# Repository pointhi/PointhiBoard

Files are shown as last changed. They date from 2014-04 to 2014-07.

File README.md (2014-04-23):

PointhiBoard
============

A Raspberry Pi board which is optimized for standalone robotic and automation applications

**Licence:** GNU GPLv3

**work status:** still in Developing

###Required Software

* Eagle V6 or higher
* XC8-Compiler from Microchip

PointhiBoard Bootscreen

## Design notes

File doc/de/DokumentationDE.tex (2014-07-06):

\documentclass[a4paper,10pt]{article}
%\documentclass[a4paper,10pt]{scrartcl}

\usepackage[utf8]{inputenc}

\usepackage{multirow}

\usepackage{graphicx}
  \graphicspath{ {../images/} }
  
\usepackage{color}
  \definecolor{lbcolor}{rgb}{0.9,0.9,0.9}
  \definecolor{lbkeywordcolor}{rgb}{0,0,0.89}
  \definecolor{lbcommentcolor}{rgb}{0.58,0.58,0.58}
  \definecolor{lbstringcolor}{rgb}{0.8,0.48,0}
  \definecolor{pathcolor}{rgb}{0.4,0.4,0.4}

\usepackage{listings}
\lstset{
  tabsize=4,
  basicstyle=\ttfamily,
  showstringspaces=false,
  backgroundcolor=\color{lbcolor},  
  keywordstyle=\color{lbkeywordcolor},
  commentstyle=\color{lbcommentcolor},
  stringstyle=\color{lbstringcolor},
  breaklines=true,
  %frame=single,
  columns=fullflexible,
  xleftmargin=0.5cm,
  xrightmargin=0.5cm,
  framexleftmargin=0.25cm,
  framexrightmargin=0.25cm,
  %prebreak={\\}
}

%\lstdefinelanguage{bash} {
%  morekeywords={sudo,echo}
%}

\newcommand{\path}[1]{\textcolor{pathcolor}{\textbf{#1}}} %texttt

\makeatletter
\def\blfootnote{\xdef\@thefnmark{}\@footnotetext}
\makeatother

\usepackage{verbatim}

\usepackage{hyperref}
\hypersetup{
  colorlinks=true,
  linkcolor=black
}

\title{PointhiBoard Dokumentation}
\author{Thomas Pointhuber}
\date{}

\pdfinfo{
  /Title    (Pointhi Board Dokumentation)
  /Author   (Thomas Pointhuber)
  /Creator  (Thomas Pointhuber)
  /Producer ()
  /Subject  ()
  /Keywords (Raspberry Pi Shield)
}

\begin{document}
\maketitle

\pdfbookmark{\contentsname}{toc}

\tableofcontents

\section{Einleitung}

Der Raspberry Pi ist ein einfacher Einplatinencomputer, welcher ideal für komplexe Steuerungs-/Regelungs- aufgaben im Bereich der Robotik, Hausautomatisierung, und vielen anderen Bereichen ist.\\
Er zeichnet sich durch einen niedrigen Stromverbrauch in Verbindung mit einer großen Anzahl von Schnittstellen, angefangen von USB und LAN über Bussysteme wie SPI und I2C bis zu einzelnen Digitalen Ausgängen, welche mithilfe von Linux angesprochen werden können.\\
Die Nutzung der Low-Level Schnittstellen die an einer Stiftleiste herausgeführt sind gestaltet sich aber nicht immer Trivial, auch ist die Spannungsversorgung in Robotern nicht für eine zusätzliche Last mit bis zu 1A ausgelegt. Aus diesem und anderen Gründen soll daher ein Erweiterungsboard für den Raspberry Pi entstehen welches grundlegende Aufgaben übernimmt, die für Systeme in Steuerungssystemen notwendig erscheinen.\\
%\includegraphics[width=\textwidth]{pointhiboard_booting}

\newpage

\subsection{Überblick der Funktionen}
Die Grundlegenden Ausstattung, die die Erweiterungsplatine besitzen soll, bzw. bereits besitzt.
\begin{itemize}
 \item Effizienter Spannungsregler der Spannungen zwischen 7V-25V auf saubere 5V regelt
 \item Pegelwandler für I2C, um sich mit normaler 5V-Hardware  zu verbinden
 \item Schnittstelle für LCD-Touch-Display auf SPI-Basis, welche später auch für SPI$\rightarrow$CAN Konverter benutzt werden kann.
 \item Echtzeituhr (RTC), weil der Raspberry Pi keine besitzt, diese aber für diverse Anwendungen benötigt werden
 \item Spannungsüberwachung und Überstromschutz, um auch mit LiPo-Versorgung sicher zu arbeiten (Tiefentladeschutz)
 \item Digitale Ein/Ausgänge und 8 Analoge Eingänge um ohne zusätzlicher Erweiterungsboard bereits einfache Steuerungen zu realisieren.
 \item RS232-TTL Schnittstelle
 \item RN-Standard Steckverbinder mit Verriegelung, für einfache Erweiterbarkeit und Betriebssicherheit.
\end{itemize}

\section{Technische Spezifikationen}

\subsection{Mechanische Spezifikationen}

\begin{center}
    \begin{tabular}{| l | l | l | l | l |}
    \hline
    \textbf{Characteristic} & \textbf{Min} & \textbf{Typ.} & \textbf{Max} & \textbf{Units} \\ \hline
    Breite & - & 60 & - & mm \\ \hline
    Länge & - & 110 & - & mm \\ \hline
    
    \end{tabular}
\end{center}

\subsection{Elektrischer Spezifikationen}

\begin{center}
    \begin{tabular}{| l | l | l | l | l | l | l |}
    \hline
    \textbf{Characteristic} 	& \textbf{Symbol} 	& \textbf{Test Conditions} 	& \textbf{Min} 	& \textbf{Typ.} & \textbf{Max} 	& \textbf{Units} \\ \hline
    Versorgungsspannung 	& $U_{IN}$ 		& 				& 8 		& 12 		& 20 		& $V$ \\ \hline
    Eingangsstrom 		& $I_{IN}$ 		& 				& - 		& - 		& 8 		& $A$ \\ \hline
    Leerlaufstrom 		& $I_{IN0}$ 		& $U_{IN} = 12V$		& - 		& 20 		& - 		& $mA$ \\ \hline
    Ausgangsspannung, 5V	& $U_{5V}$ 		& 				& 4.95 		& 5 		& 5.05 		& $V$ \\ \hline
    Ausgangsstrom, 5V 		& $I_{5V}$ 		& 				& - 		& - 		& 2.5 		& $A$ \\ \hline
    Umgebungstemperatur 	&  			& 				& -10 		& 20 		& 50 		& $^\circ C$ \\ \hline
    \end{tabular}
\end{center}

\subsubsection{Steckverbinder}

\paragraph{I2C} \mbox{} \\
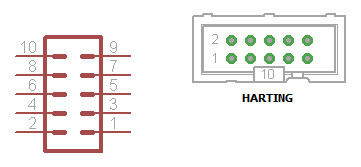
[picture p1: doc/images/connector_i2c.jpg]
 \\
Der I2C-Stecker dient dazu Peripherie mit Spannung und einem Busdystem zu verbinden (I2c). Er ist gemäß den RN-Definitionen\footnote{\url{http://www.rn-wissen.de/index.php/RN-Definitionen\#I2C-Bus_Stecker}} belegt.
\begin{center}
    \begin{tabular}{| l | l |}
    \hline
    Pin 1 	& SCL (Taktleitung) \\ 
    Pin 3	& SDA (Datenleitung) \\
    Pin 5,7 	& +5V \\ 
    Pin 9 	& Batteriespannung \\ 
    Pin 2,4,6,8	& GND \\
    Pin 10 	& INT \\ \hline
    \end{tabular}
\end{center}

\paragraph{ICSP} \mbox{} \\
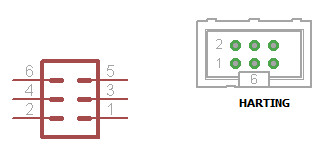
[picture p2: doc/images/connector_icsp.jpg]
 \\
Der ICSP-Verbinder ist dazu vorhanden um den PIC mit einer Firmware beschreiben zu können. Er ist nicht als 5-Poligen Stiftleiste wie er oft realisiert wird ausgeführt, sondern als verpolungssicherer 6-Poliger Steckverbinder wie ich ihn in allen meinen anderen Schaltungen auch verwende.
\begin{center}
    \begin{tabular}{| l | l |}
    \hline
    Pin 1 	& PGD \\ 
    Pin 2,4	& VSS (GND) \\
    Pin 3 	& PGC \\ 
    Pin 5 	& VDD (+5V) \\ 
    Pin 6	& MCLRE/VPP \\ \hline
    \end{tabular}
\end{center}

\paragraph{8-Bit Datenportstecker} \mbox{} \\
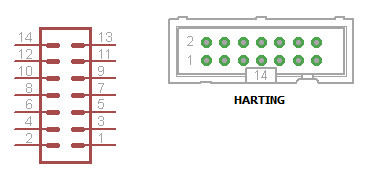
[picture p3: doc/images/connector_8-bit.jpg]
 \\
Es können hier 8 Signale übertragen werden, welche je nach Steckverbinder Analog oder Digital sein können.
\begin{center}
    \begin{tabular}{| l | l |}
    \hline
    Pin 1...8 	& PIN 0...7 \\ 
    Pin 9,11	& +5V \\
    Pin 10,12,14& GND \\ 
    Pin 13 	& Batteriespannung \\ \hline
    \end{tabular}
\end{center}

\paragraph{RS232-TTL} \mbox{} \\
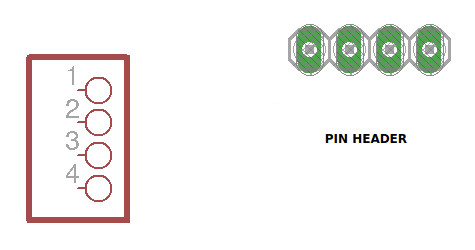
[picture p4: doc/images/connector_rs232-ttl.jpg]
 \\
Der RS232-TTL-Stecker ist gemäß den RN-Definitionen\footnote{\url{http://www.rn-wissen.de/index.php/RN-Definitionen\#RS232_TTL_Stecker}} belegt.
\begin{center}
    \begin{tabular}{| l | l |}
    \hline
    Pin 1 	& RX \\ 
    Pin 2	& TX \\
    Pin 3	& GND \\ 
    Pin 4 	& +5V \\ \hline
    \end{tabular}
\end{center}

%\section{Prototyp}

%Ich habe bereits einen Prototypen gebaut, der die grundlegende Funktionalität abdeckt, und als Testsystem dient. Das Linux-System bootet, und auch der Steuerungs-Chip auf dem Board arbeitet einwandfrei. Bis zu diesem Stand musste ich aber viele Probleme lösen, und deshalb wird bald eine neue Platine entstehen in der diese Probleme nicht mehr existent sind. \\ \\
%\includegraphics[width=\textwidth]{pointhiboard_prototype_booting} \\
%Das Board bekam bereits ein neues Layout, welches unter anderem Masseschleifen entfernte, und Status LEDs beinhaltet, die ein einfaches Debuggen ermöglichen sollen. Auch wurde der Schaltregler optimiert, welcher für das Board essentiell ist. \\

\newpage
\section{Platine}

\subsection{Übersicht}

\subsubsection{Top-Layer}

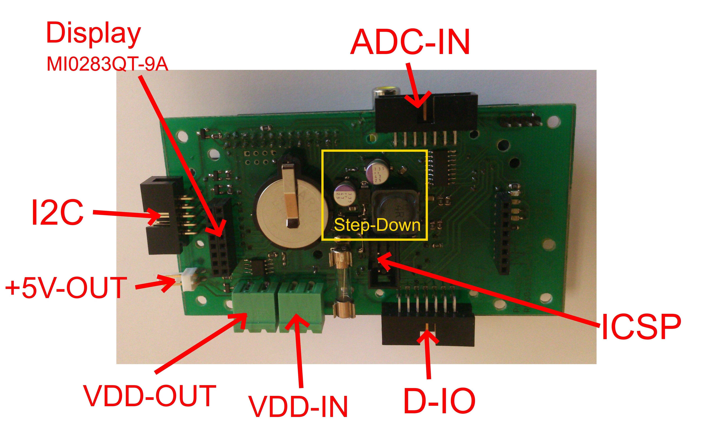
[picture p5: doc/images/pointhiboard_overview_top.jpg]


\subsubsection{Bottom-Layer}

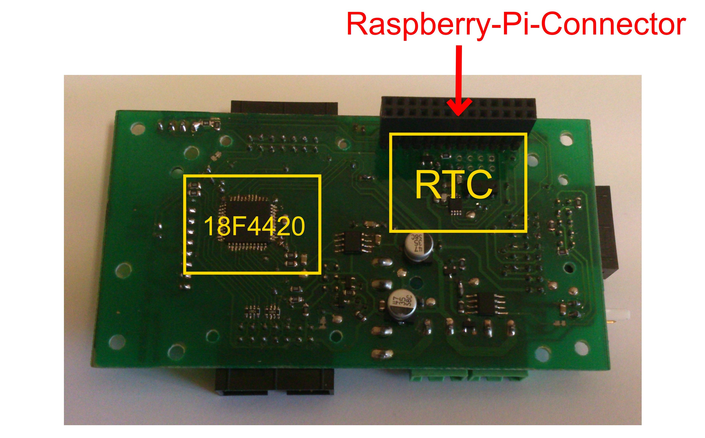
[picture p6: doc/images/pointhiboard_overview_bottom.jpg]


\newpage
\subsection{Bestückung}

Es sollten zuerst alle SMD-Bauteile auf dem Bottom-Layer, danach die auf dem Top-Layer bestückt werden. Am Schluss werden noch alle Steckverbinder und die Batteriehalterung angelötet, wobei die große Buchsenleiste, die mit dem Raspberry Pi verbunden wird als letztes angelötet werden sollte. 

\subsubsection{Top-Layer}

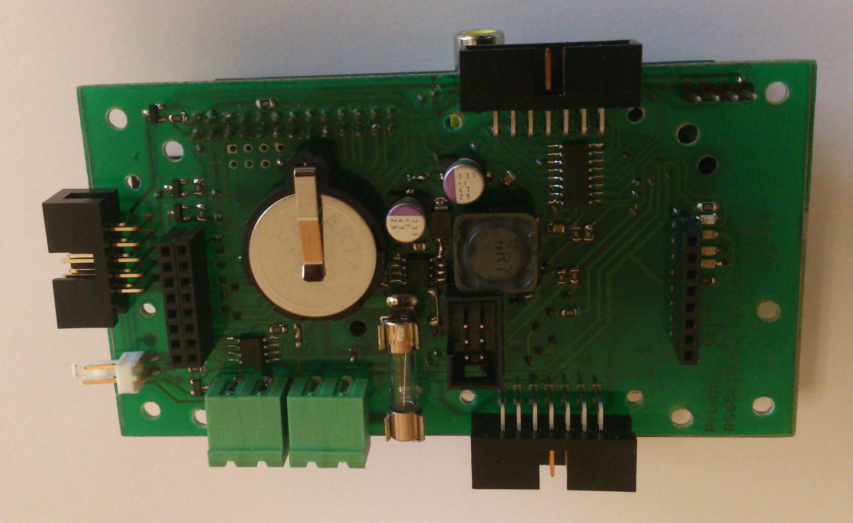
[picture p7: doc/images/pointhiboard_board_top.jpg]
 \\

\subsubsection{Bottom-Layer}

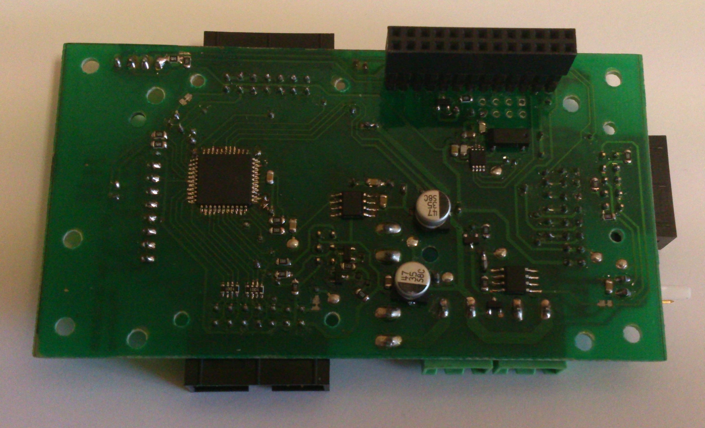
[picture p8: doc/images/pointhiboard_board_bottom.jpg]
 \\

\newpage

\section{Inbetriebnahme der Hardware}

\subsection{Flashen des Steuer-PIC}

Es wird ein ICSP-Programmiergerät, welches einen PIC18F4420 flashen kann am Board angeschlossen (ICSP-Stecker). Der PIC sollte korrekt erkannt werden, und kann dann mit der Firmware beschrieben werden.

\subsection{Testen des Step-Down-Wandler}

\begin{enumerate}
 \item Es wird am Eingang des Board ein Netzteil mit folgenden Einstellungen angeschlossen: $I_{max} \simeq 100mA, U_a = 5V$
 \item Am Spannungs-Ausgang für den Raspbery Pi wird ein Multimeter angeschlossen, welches eine Spannung von ungefähr 5V anzeigen sollte.
 \item Jetzt wird die Spannung des Netzteiles langsam auf etwa 10-12V gesteigert, die Spannung am Multimeter darf dabei eine Spannung von 5,1-5,2V nicht überschreiten!
Falls die Spannung höher als etwa 5,2V steigen sollte funktioniert der Step-Down-Wandler nicht ordnungsgemäß. Der Step-Down-Wandler auf der Platine muss überprüft und wenn möglich repariert werden. Eine zu hohe Spannung am 5V-Spannungskreis könnte ansonsten zu einer Beschädigung diverser Bauteile auf dieser, und anderen angeschlossenen Platinen führen.
\end{enumerate}

\subsection{Fehlerbehebung}

\begin{center}
    \begin{tabular}{| l | p{6cm} |}
    \hline
    \textbf{Problem}	& \textbf{Fehlerursache} \\ \hline
    \multirow{3}{*}{Keine der Status-LED leuchtet auf}
	& Board nicht korrekt angeschlossen \\ \cline{2-2}
	& Sicherung durchgebrannt \\ \cline{2-2}
	& PIC nicht/falsch geflasht \\
    \hline
    \multirow{2}{*}{+5V, PWR-Led leuchtet nicht}
	& Tiefentladeschutz aktiv (kurz aufleuchtende STAT-LED) \\ \cline{2-2}
	& MOSFET schaltet nicht durch \\
    \hline
    \end{tabular}
\end{center}

\subsection{Testen der Hardware}

Der PIC wird mit der speziellen TEST-Firmware beschrieben\footnote{siehe Flashen des Steuer-PIC}. Dann werden die beiden 14-Poligen Stiftleisten 1:1 miteinander verbunden. Sobald das Board mit Spannung versorgt wird startet die Testroutine. Solange die Testroutine aktiv ist blinken beide Status-LEDs schnell. Wenn diese dann erfolgreich war, Leuchtet ``STAT'' dauerhaft. Falls die Testroutine fehlschlägt fängt die LED ``INFO'' zu blinken an.

\newpage

\section{Inbetriebnahme der Software}

Hier ist die Konfiguration einen Raspberry Pi der 2. Revision beschrieben. Wenn ein Raspberry Pi der 1. Revision verwendet wird muss i2c-1 durch i2c-0 ersetzt werden! Das verwendete Distribution ist das oft verwende Wheezy, bei Arch und anderen Linux Derivaten kann die Konfiguration abweichen!

\subsection{Aktivieren von I2C und SPI}

\begin{enumerate}
 \item In der Datei \path{/etc/modprobe.d/raspi-blacklist.conf} werden die beiden Schnittstellen aktiviert, indem die beiden Zeilen wie folgt auskommentiert werden:
    \begin{lstlisting}
#blacklist spi-bcm2708
#blacklist i2c-bcm2708
    \end{lstlisting}
 \item In der Datei \path{/etc/modules} werden dann folgende Module hinzugefügt:
    \begin{lstlisting}
snd-bcm2835
i2c-bcm2708 
i2c-dev     
    \end{lstlisting}
\end{enumerate}

\subsection{Aktivieren der I2C-Echtzeituhr}
\blfootnote{\url{http://www.100randomtasks.com/raspberry-pi-rtc}}

\begin{enumerate}
 \item Hinzufügen der folgenden Zeile in der Datei \path{/etc/modules}:
    \begin{lstlisting}
i2c:mcp7941x
    \end{lstlisting}
 \item Es werden 2. Zeilen in der Datei \path{/etc/rc.local} hinzugefügt (vor dem Befehl ``exit 0``):
    \begin{lstlisting}[language=sh]
echo mcp7941x 0x6f > /sys/class/i2c-dev/i2c-1/device/new_device 
hwclock -s
    \end{lstlisting}
 \item Jetzt kann man die fake-hwclock deaktivieren
    \begin{lstlisting}[language=sh]
sudo update-rc.d fake-hwclock remove
    \end{lstlisting}
 \item Jetzt wird der Raspberry Pi neu gestartet, und dann die aktuelle zeit wie folgt in UTC gesetzt (natürlich das Datum durch das aktuelle ersetzten): 
    \begin{lstlisting}[language=sh]
sudo date -s "9 JAN 2014 12:00:00"
    \end{lstlisting}
 \item Beim Herunterfahren wird dann ab sofort die Zeit in die Echtzeituhr geschrieben, und beim nächsten Starten daraus ausgelesen.
\end{enumerate}

\subsubsection{Fehlerbehebung}
Falls wie bei mir die folgende Fehlermeldung hwclock: ''ioctl(RTC\_RD\_TIMEE) to /dev/rtc0 to read the time failed: Invalid argument`` auftritt, werden einfach die folgenden Befehle in die Shell der Reihe nach eingegeben:
\begin{lstlisting}[language=sh]
hwclock -w
hwclock -s
hwclock -r
\end{lstlisting}

\subsection{Aktivieren des LCD-Touch-Displays (MI0283QT-9A)}
\blfootnote{\url{http://lallafa.de/blog/2013/07/watterotts-new-rpi-shieldbridge}}
\blfootnote{\url{http://busware.de/tiki-index.php?page=CCD_Installation}}
\blfootnote{\url{http://www.raspberrypirobot.com/1-8-tft-lcd-display-raspberry-pi-expansion-board/}}

\begin{enumerate}
 \item Download ''FBTFT drivers as loadable modules. See 'Step-by-step' for loading drivers.'' \url{https://github.com/notro/fbtft/wiki#image-download}
    \begin{lstlisting}
sudo wget https://raw.github.com/Hexxeh/rpi-update/master/rpi-update -O /usr/bin/rpi-update && sudo chmod +x /usr/bin/rpi-update
    \end{lstlisting}
    
 \item Dann wird der Repository-Pfad geändert und ein update durchgeführt.
    \begin{lstlisting}
sudo REPO_URI=https://github.com/notro/rpi-firmware rpi-update
sudo shutdown -r now
    \end{lstlisting}
 
 \item In der Datei \path{/etc/modules} werden dann folgende Module hinzugefügt:
    \begin{lstlisting}
fbtft_device
ads7846_device
    \end{lstlisting}
    
 \item In der Datei \path{/etc/modprobe.d/pointhiboard.conf} werden dann folgende Optionen definiert:
    \begin{lstlisting}
options ads7846_device cs=0 speed=2000000 model=7846 x_min=250 x_max=3780 y_min=160 y_max=3930 pressure_max=255 x_plate_ohms=60 gpio_pendown=25 keep_vref_on=1 swap_xy=1 
options fbtft_device cs=1  speed=16000000 fps=25 name=mi0283qt-9a gpios=reset:23,led:24 rotate=90
    \end{lstlisting}
    
 \item In der Datei \path{/etc/X11/xinit/xinitrc} wird dann folgendes vor . /etc/X11/Xsession eingefügt:%# Touchpanel: Invert X and Y axis
    \begin{lstlisting}[language=sh]
DISPLAY=:0 xinput --set-prop 'ADS7846 Touchscreen' 'Evdev Axis Inversion' 1 1
    \end{lstlisting}
    
 \item Damit die Konsole beim booten auf dem Display dargestellt wird, muss folgendes am ende in \path{/boot/cmdline.txt} hinzugefügt werden:
    \begin{lstlisting}
fbcon=map:10 fbcon=font:ProFont6x11
    \end{lstlisting}
\end{enumerate}

\newpage
\section{Linux-Bibliotek}

Um auf den Controller zuzugreifen kann man meine kleine Bibliotek nutzen, welche alle notwendigen Funktionen besitzt um mit dem Steuerpic zu kommunizieren.

\subsection{Installation}

\begin{enumerate}
 \item Der Inhalt des Ordners \path{lib} wird auf die SD-Karte des RaspberryPi kopiert (mithilfe eines USB-Stick, scp, FTP,...).
 
 \item Es wird in das Verzeichnis \path{libPointhiBoard} gewechselt, und danach wird die Bibliotek gebaut:
    \begin{lstlisting}[language=sh]
make clean CONF=Release
make build CONF=Release
    \end{lstlisting}
    
  \item Dann kopiert man die erstelle Bibliotek und deren Include-Datei in ein anderes Verzeichnis:
    \begin{lstlisting}[language=sh]
sudo cp dist/Release/GNU-Linux-x86/libPointhiBoard.so /usr/local/lib/libPointhiBoard.so
sudo cp src/PointhiBoard.h /usr/local/include/PointhiBoard.h
    \end{lstlisting}
    
  \item Falls \path{/usr/local/lib} beim kompilieren von Software nicht durchsucht wird muss dieser pfad noch in \path{/etc/ld.so.conf} hinzugefügt werden:
    \begin{lstlisting}[language=sh]
sudo sh -c "echo '/usr/local/lib' >> /etc/ld.so.conf"
sudo ldconfig
    \end{lstlisting}   
    
\end{enumerate}

\newpage
\section{PIC-Firmware}

\subsection{I2C}

\subsubsection{Schreiben}

Das erste übertragene Byte setzt den Schreib/Lese-Index fest. Dieser wird dann nach jedem weiteren Schreib/Lesebefehl jeweils um 1 inkrementiert, solange er nicht durch eine neue Schreibübertragung neu gesetzt wurde.

\begin{center}
    \begin{tabular}{| l | l | l |}
    \hline
    \textbf{Index} 	& \textbf{Aktion} 	& \textbf{Information} \\ \hline
    0x01 		& Setze TRISB 		& 1... Eingang, 0... Ausgang \\ \hline
    0x0F 		& Setze PORTB 		& 1... High, 0... Low \\ \hline
    \end{tabular}
\end{center}

\subsubsection{Lesen}

Je nach aktuellem Wert des Schreib/Lese-Index wird die jeweilige Variable ausgelesen, und danach der Schreib/Lese-Index um 1. Inkrementiert.

\begin{center}
    \begin{tabular}{| l | l | l |}
    \hline
    \textbf{Index}	& \textbf{Aktion} 		& \textbf{Information} \\ \hline
    0x01 		& Lese TRISB 			& 1... Eingang, 0... Ausgang \\ \hline
    0x0F 		& Lese PORTB 			& 1... High, 0... Low \\ \hline
    0x10 		& ADC - 0 VOLTAGE-HIGH-BYTE 	& \\ \hline
    0x11 		& ADC - 0 VOLTAGE-LOW-BYTE 	& \\ \hline
    0x12 		& ADC - 1 VOLTAGE-HIGH-BYTE 	& \\ \hline
    0x13 		& ADC - 1 VOLTAGE-LOW-BYTE 	& \\ \hline
    0x14 		& ADC - 2 VOLTAGE-HIGH-BYTE 	& \\ \hline
    0x15 		& ADC - 2 VOLTAGE-LOW-BYTE 	& \\ \hline
    0x16 		& ADC - 3 VOLTAGE-HIGH-BYTE 	& \\ \hline
    0x17 		& ADC - 3 VOLTAGE-LOW-BYTE 	& \\ \hline
    0x18 		& ADC - 4 VOLTAGE-HIGH-BYTE 	& \\ \hline
    0x19 		& ADC - 4 VOLTAGE-LOW-BYTE 	& \\ \hline
    0x1A 		& ADC - 5 VOLTAGE-HIGH-BYTE 	& \\ \hline
    0x1B 		& ADC - 5 VOLTAGE-LOW-BYTE 	& \\ \hline
    0x1C 		& ADC - 6 VOLTAGE-HIGH-BYTE 	& \\ \hline
    0x1D 		& ADC - 6 VOLTAGE-LOW-BYTE 	& \\ \hline
    0x1E 		& ADC - 7 VOLTAGE-HIGH-BYTE 	& \\ \hline
    0x1F 		& ADC - 7 VOLTAGE-LOW-BYTE 	& \\ \hline
    0x20 		& ADC - VCC VOLTAGE-HIGH-BYTE 	& \\ \hline
    0x21 		& ADC - VCC VOLTAGE-LOW-BYTE 	& \\ \hline
    0x22 		& ADC - +5V VOLTAGE-HIGH-BYTE 	& \\ \hline
    0x23 		& ADC - +5V VOLTAGE-LOW-BYTE 	& \\ \hline
    \end{tabular}
\end{center}

\newpage
\section{Anhänge}

\subsection{Schaltplanteile}

\subsubsection{Step-Down-Wandler}

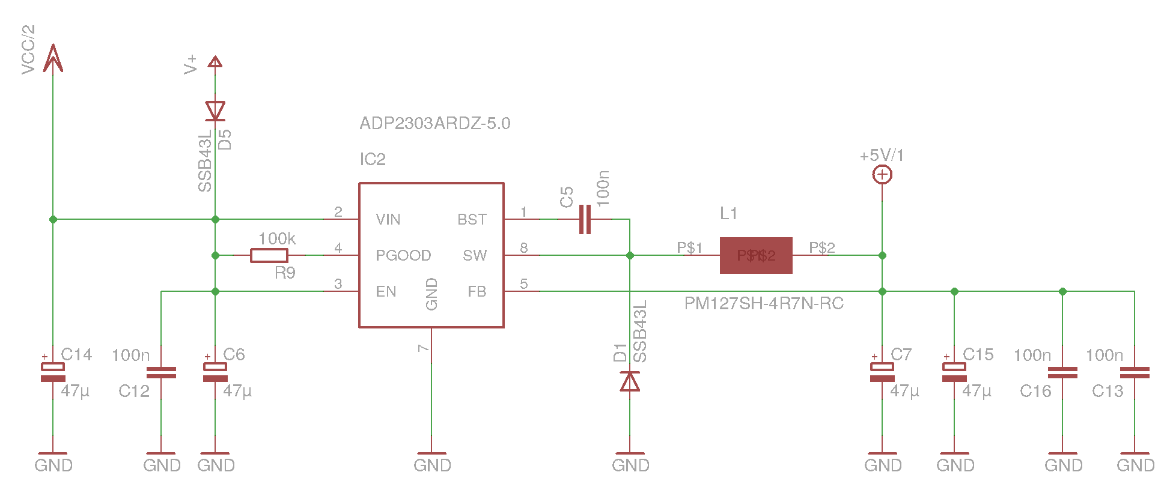
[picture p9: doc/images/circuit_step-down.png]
 \\
Der Step-Down Wandler entspricht großteils der Beispielbeschaltung und Dimensionierung im Datenblatt. Abweichend zum Datenblatt wurden größere Kapazitäten am Eingang und Ausgang definiert, welche durch Paralellschaltung mehrerer Kondensatoren realisiert wurde um den ESR niedrig zu halten. \\\\
Die Spule ist Geschirmt um den Wirkungsgrad des Step-Down Wandlers niedrig zu halten, und besitzt einen Maximalstrom von etwa 8A um bei Strömen bis 3A sauber arbeiten zu können (Die Induktivität eines Schaltreglers sollte etwa 2-3 mal so viel aushalten wie eigentlich benötigt).

\subsubsection{Echtzeituhr}

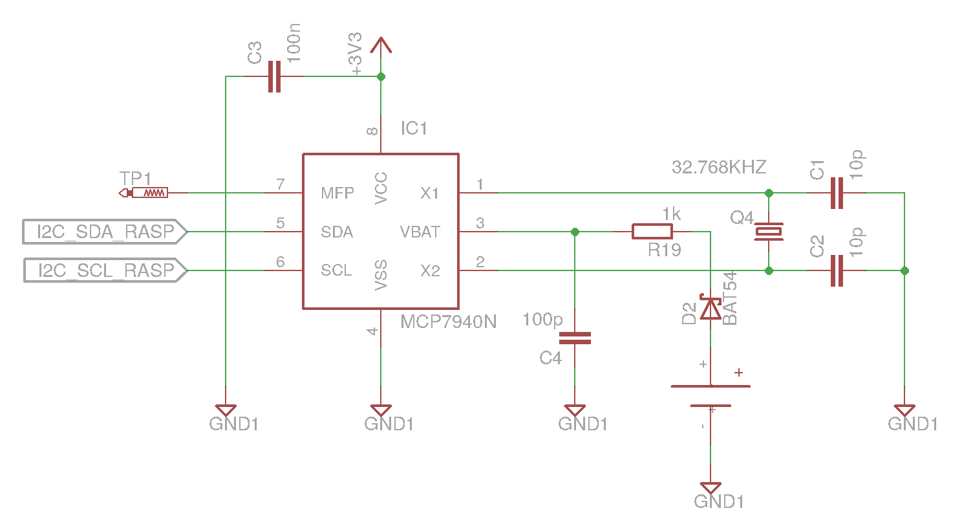
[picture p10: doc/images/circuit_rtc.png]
 \\
Es wird eine günstige Echtzeituhr genutzt, welche dank Lithium-Batterie auch ohne Versorgungsspannung ihre Zeit nicht verliert. Sie ist am 3,3V Bereich des I2C-Bus angeschlossen und entspricht in der Dimensionierung der Beispielbeschaltung.

\subsubsection{FET-Treiber}

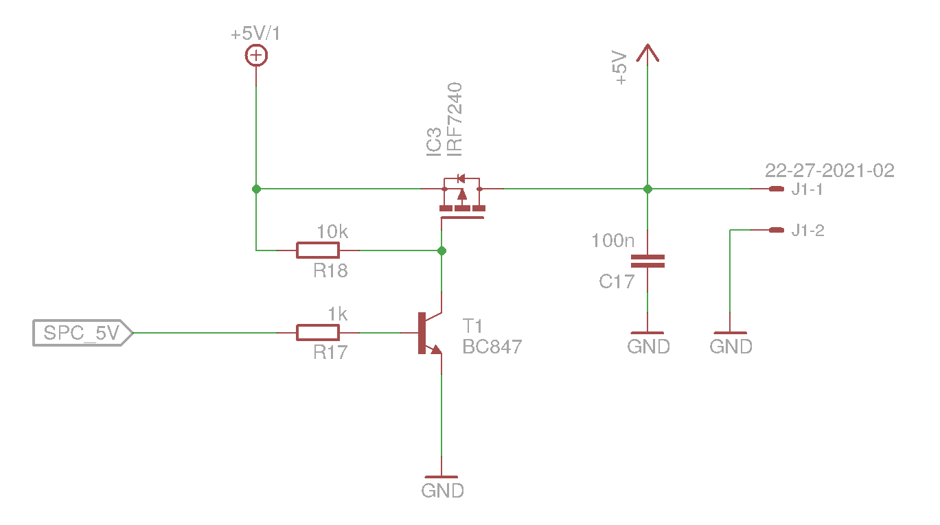
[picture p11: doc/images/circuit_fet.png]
 \\
Das ist eine grundlegende Schaltung um Spannungen ohne große Schaltverluste schalten zu können. Im Board wird diese Schaltung 2. Mal verwendet um im Tiefentladefall die Peripherie vollständig zu deaktivieren (inkl. RaspberryPi und allen an Steckverbinder angeschlossene Module)

\subsubsection{I2C-Steckverbinder + Pull-Up}

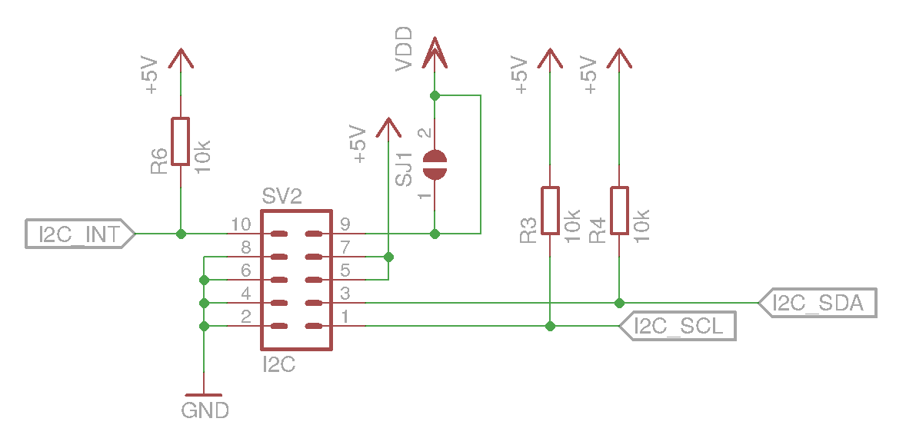
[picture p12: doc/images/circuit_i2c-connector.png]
 \\
Der I2C-Steckverbinder ist die Hauptschnittstelle zum Anbinden zusätzlicher Peripherie. Sie ist nach RN-Standard belegt um eine kompalibität mit anderen Platinen zu gewährleisten.

\newpage
\subsection{Bestückungsplan}

\subsubsection{Top-Layer}

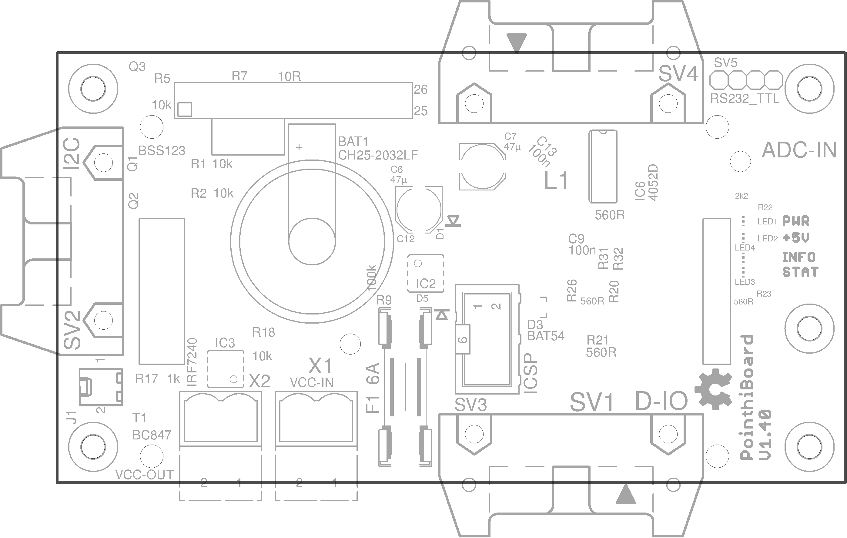
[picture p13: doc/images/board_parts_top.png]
 \\

\subsubsection{Bottom-Layer}

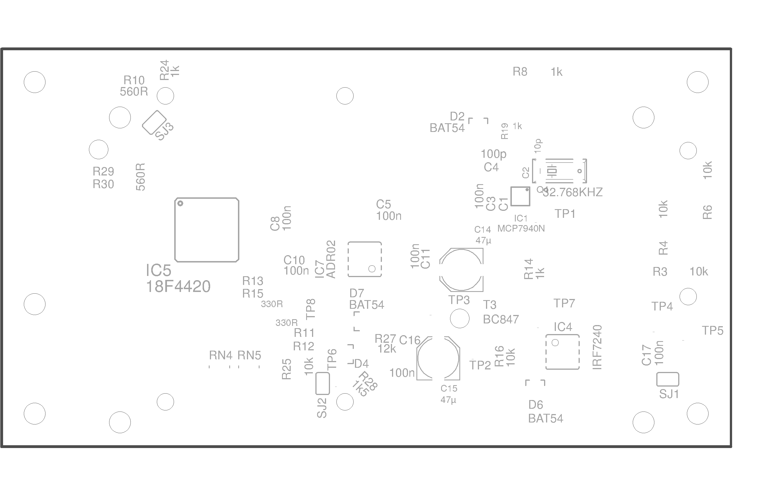
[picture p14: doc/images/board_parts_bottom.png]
 \\

\newpage
\subsection{Stückliste}

\verbatiminput{../partlist.txt}

\newpage
\subsection{Bedienung des BusPirat}

\blfootnote{\url{http://dangerousprototypes.com/docs/I2C}}

Der BusPirat\footnote{\url{http://dangerousprototypes.com/bus-pirate-manual}} ist ein kompaktes Entwicklermodul zum Debuggen diverser Bussysteme. Er ist Open-Hardware, und kann in der Standardversion diverse Protokolle wie I2C, SPI, RS232, 1-Wire mitlesen und auch selber eigene Daten versenden. \\\\
Ich habe den BusPirat zum debuggen des I2C-Codes benutzt, und das hier stellt eine kurze Anleitung zur Inbetriebnahme dar.

\subsubsection{Nötige Schritte zur Inbetriebnahme des I2C-Debugger}

\begin{enumerate}
 \item Einrichten des Terminals auf Ubuntu\footnote{\url{http://jumptuck.com/2010/01/20/using-the-bus-pirate-with-ubuntu}}
 
 \item Konfiguration des BusPiraten über minicom
\begin{lstlisting}
m
4
3
w
p
    \end{lstlisting}

 \item Herstellung der Elektrischen Verbindungen zum Board (SDA, SCL, GND) 
 
\end{enumerate} 

\subsubsection{Arbeiten mit dem I2C-Debugger}

\begin{itemize}
 \item Suche die mit dem Bus verbundenen I2C-Bausteine:
    \begin{lstlisting}
(1)
    \end{lstlisting}
 \item I2C-Sniffer (bis 100kHz)
    \begin{lstlisting}
(2)
    \end{lstlisting}

  \item Schreibe Daten zu einem I2C-Baustein:
    \begin{lstlisting}
[0xC0 0x01 0x00]
    \end{lstlisting}
    Zuerst wird die Adresse geschrieben, danach kommen die zu übertragene Daten
    
\item Lese Daten von einem I2C-Baustein:
    \begin{lstlisting}
[0xC1 r]
    \end{lstlisting}
    Zuerst wird die Adresse geschrieben, danach kommt ein r:bitanzahl (funktioniert noch nicht ganz)
\end{itemize}

\begin{comment}
% nicht für die Dokumentation benötigt
\newpage
\subsection{Arbeitstage}
\begin{center}

\begin{tabular}{| l | l |}
    \hline
    \textbf{Datum} 	& \textbf{Arbeit}\\ \hline
    03.10.2013		& Hardware design 						\\ \hline
    10.10.2013 		& Teilebestellung 						\\ \hline
    17.10.2013 		& Hardwarebestückung (V1.2), Testen 				\\ \hline
    24.10.2013 		& Hardwarebestückung (V1.2), Testen 				\\ \hline
    07.11.2013 		& Hardware fertig bestücken (V1.2), erste Tests (erfolgreich) 	\\ \hline
    14.11.2013 		& Überarbeitung der Software 					\\ \hline
    21.11.2013 		& Fehlersuche, Massenbestellung					\\ \hline
    28.11.2013 		& Fehlersuche, Treiber installieren				\\ \hline
    05.12.2013 		& Fehlersuche							\\ \hline
    12.12.2013 		& Fehlersuche							\\ \hline
    19.12.2013 		& Fehler gefunden (LVP war aktiviert), Board umzeichen		\\ \hline
    09.01.2014 		& Schreiben der Dokumentation, I2C-RTC Inbetriebnahme		\\ \hline
    16.01.2014 		& optimieren der RTC, Recherche für TFT-Treiber vereinfachung	\\ \hline
    23.01.2014 		& Schreiben der Dokumentation					\\ \hline
    30.01.2014 		& diverse Arbeiten						\\ \hline
    06.02.2014 		& Hardwarebestückung (V1.3), Step-Down testen			\\ \hline
    13.02.2014 		& Hardwarebestückung (V1.3)					\\ \hline
    27.02.2014 		& Testen, Fehlersuche, Grundlegende Programmierung der Firmware	\\ \hline
    06.03.2014 		& Firmware Testen (ADC), Step-Down kaputt - Ausgelötet		\\ \hline
    13.03.2014 		& Bestellung, div. Arbeiten					\\ \hline
    20.03.2014 		& div. Arbeiten							\\ \hline
    27.03.2014 		& Platine reparieren und vervollständigt, Testplatine gelötet	\\ \hline
    03.04.2014 		& Testplatine gelötet, testen des AD-Teils der Firmware		\\ \hline
    10.04.2014 		& ADC-Routine gefixt, kalte Lötstelle bei ADC entfernt		\\ \hline
    24.04.2014 		& Dokumentation, Bestückungsplan				\\ \hline
    08.05.2014 		& Bibliotek programmieren					\\ \hline
    15.05.2014 		& Bibliotek programmieren, Beispielprogramm, Dokumentation	\\ \hline
    22.05.2014 		& Bugfix im Beispielprogramm, Dokumentation, Präsentation vorbereiten	\\ \hline
    05.06.2014 		& Präsentationen anschauen					\\ \hline
    12.06.2014 		& 								\\ \hline
    \end{tabular}
\end{center}
\end{comment}

\newpage
\subsection{Lizenz}

\verbatiminput{../../LICENSE}

\end{document}

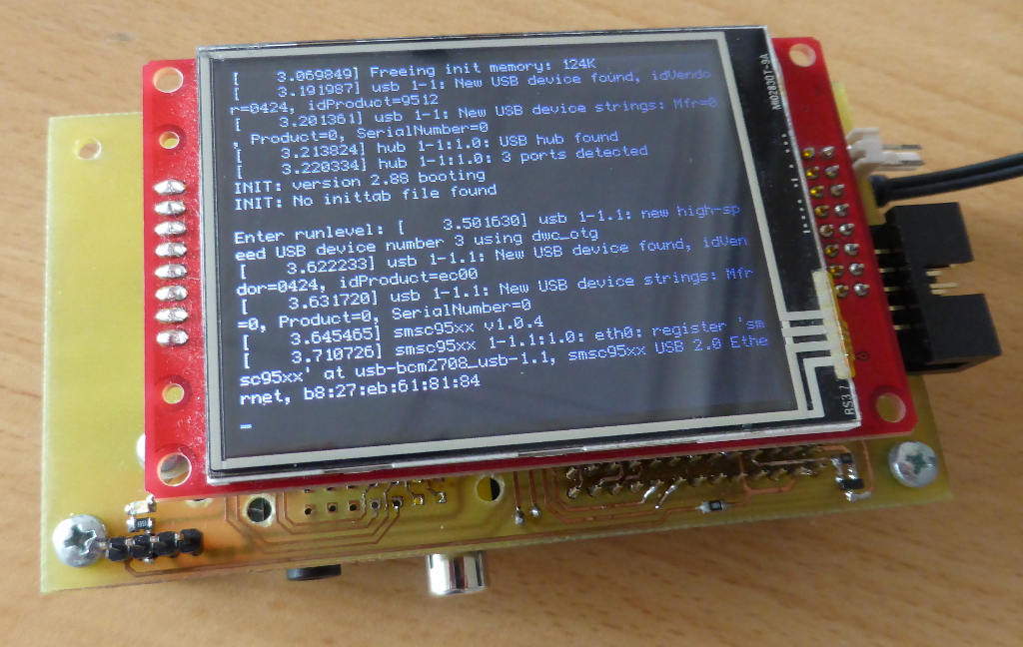
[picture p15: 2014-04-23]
doc/images/pointhiboard_prototype_booting.jpg

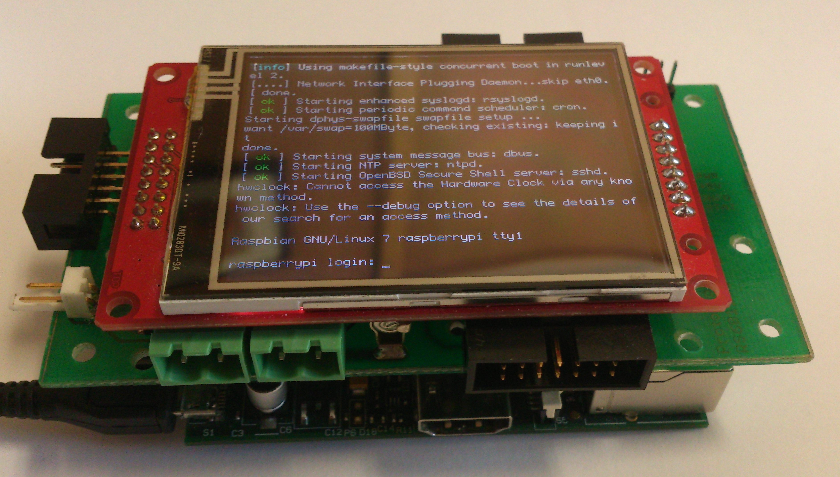
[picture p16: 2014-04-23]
doc/images/pointhiboard_booting.jpg

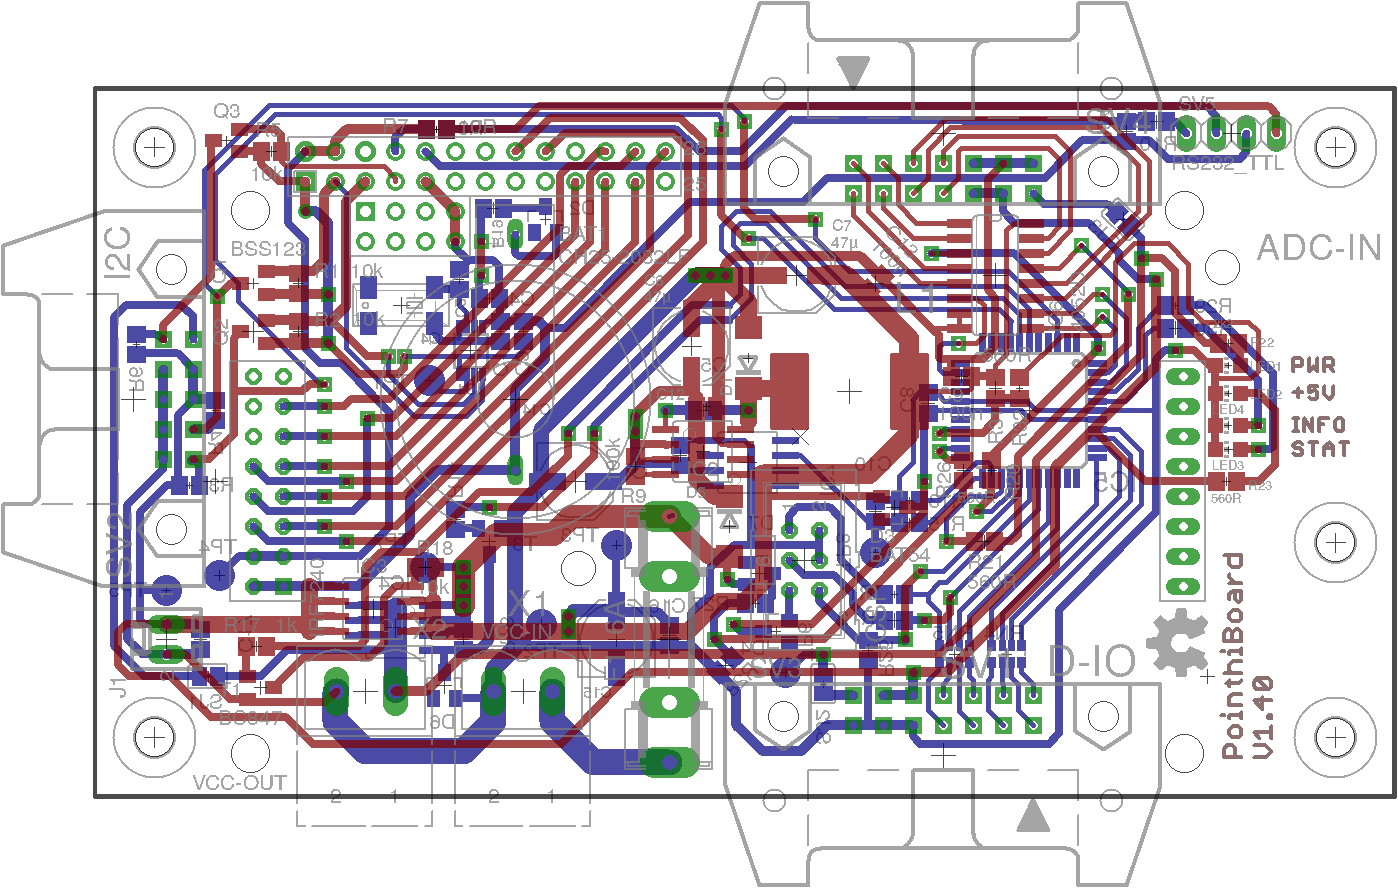
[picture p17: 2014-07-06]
doc/images/board.png

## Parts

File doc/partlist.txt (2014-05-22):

Part                Value           Package

BAT1                CH25-2032LF     CH25-2032LF
C1,C2               10p             C0805
C3,C4,C5,C8,C9,C10  100n            C0805
V11,C12,C13,C16,C17 100n            C0805
C6,C7,C14,C15       47µ             PANASONIC_D
D1                  SSB43L          DO214AA
D2,D3,D4,D6,D7      BAT54           SOT23
D5                  SSB43L          DO214AA
F1                  6A              SHK20L
IC1                 MCP7940N        MSOP8
IC2                 ADP2303ARDZ-5.0 SOIC8
IC3,IC4             IRF7240         SOIC8
IC5                 18F4420         TQFP44
IC6                 4052D           SO16
IC7                 ADR02           SOIC8
J1                  22-27-2021-02   6410-02
L1                  PM127SH-4R7N-RC PM127SH
LCD1                MI0283QT-9A     MI0283QT-9A #TODO
LED1                RED             CHIP-LED0805
LED2                GREEN           CHIP-LED0805
LED3                BLUE            CHIP-LED0805
LED4                YELLOW          CHIP-LED0805
Q1,Q2,Q3            BSS123          SOT23
Q4                  32.768KHZ       MM20SS
R7                  10R             R0805
R11,R12,R13,R15     330R            R0805
R10,R20,R21,R23,R26 560R            R0805
R29,R30,R31,R32     560R            R0805
R8,R14,R17,R19,R24  1k              R0805
R28                 1k5             R0805
R22                 2k2             R0805
R1,R2,R3,R4,R5,R6   10k             R0805
R16,R18,R25         10k             R0805
R27                 12k             R0805
R9                  100k            R0805
RN4,RN5             EXB38V          resistor-dil
SJ1,SJ2,SJ3         SJ              jumper
SV2                 I2C             3M_10L
SV1                 D-IO            3M_14L
SV4                 ADC-IN          3M_14L
SV3                 ICSP            ML6
SV5                 RS232_TTL       1X04
T1,T3               BC847           SOT23
X1                  VCC-IN          MSTBV2
X2                  VCC-OUT         MSTBV2

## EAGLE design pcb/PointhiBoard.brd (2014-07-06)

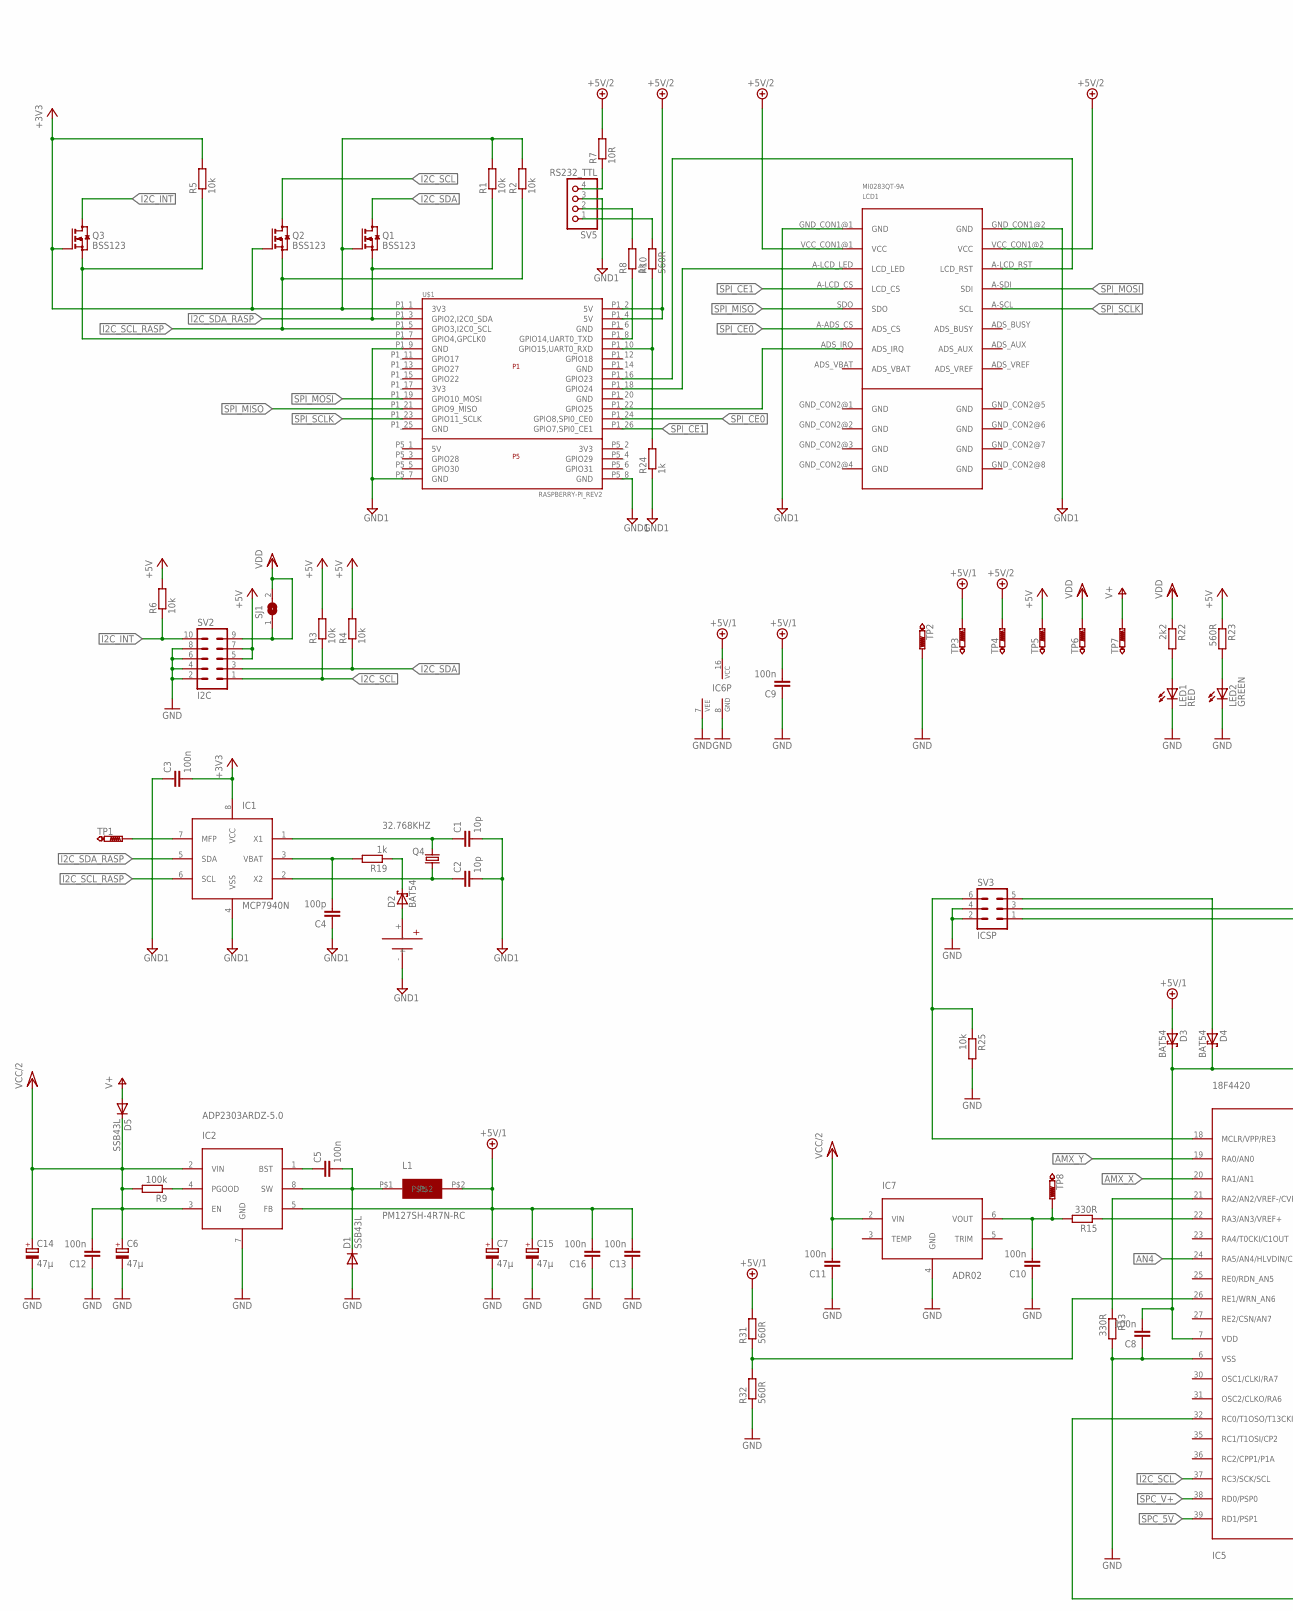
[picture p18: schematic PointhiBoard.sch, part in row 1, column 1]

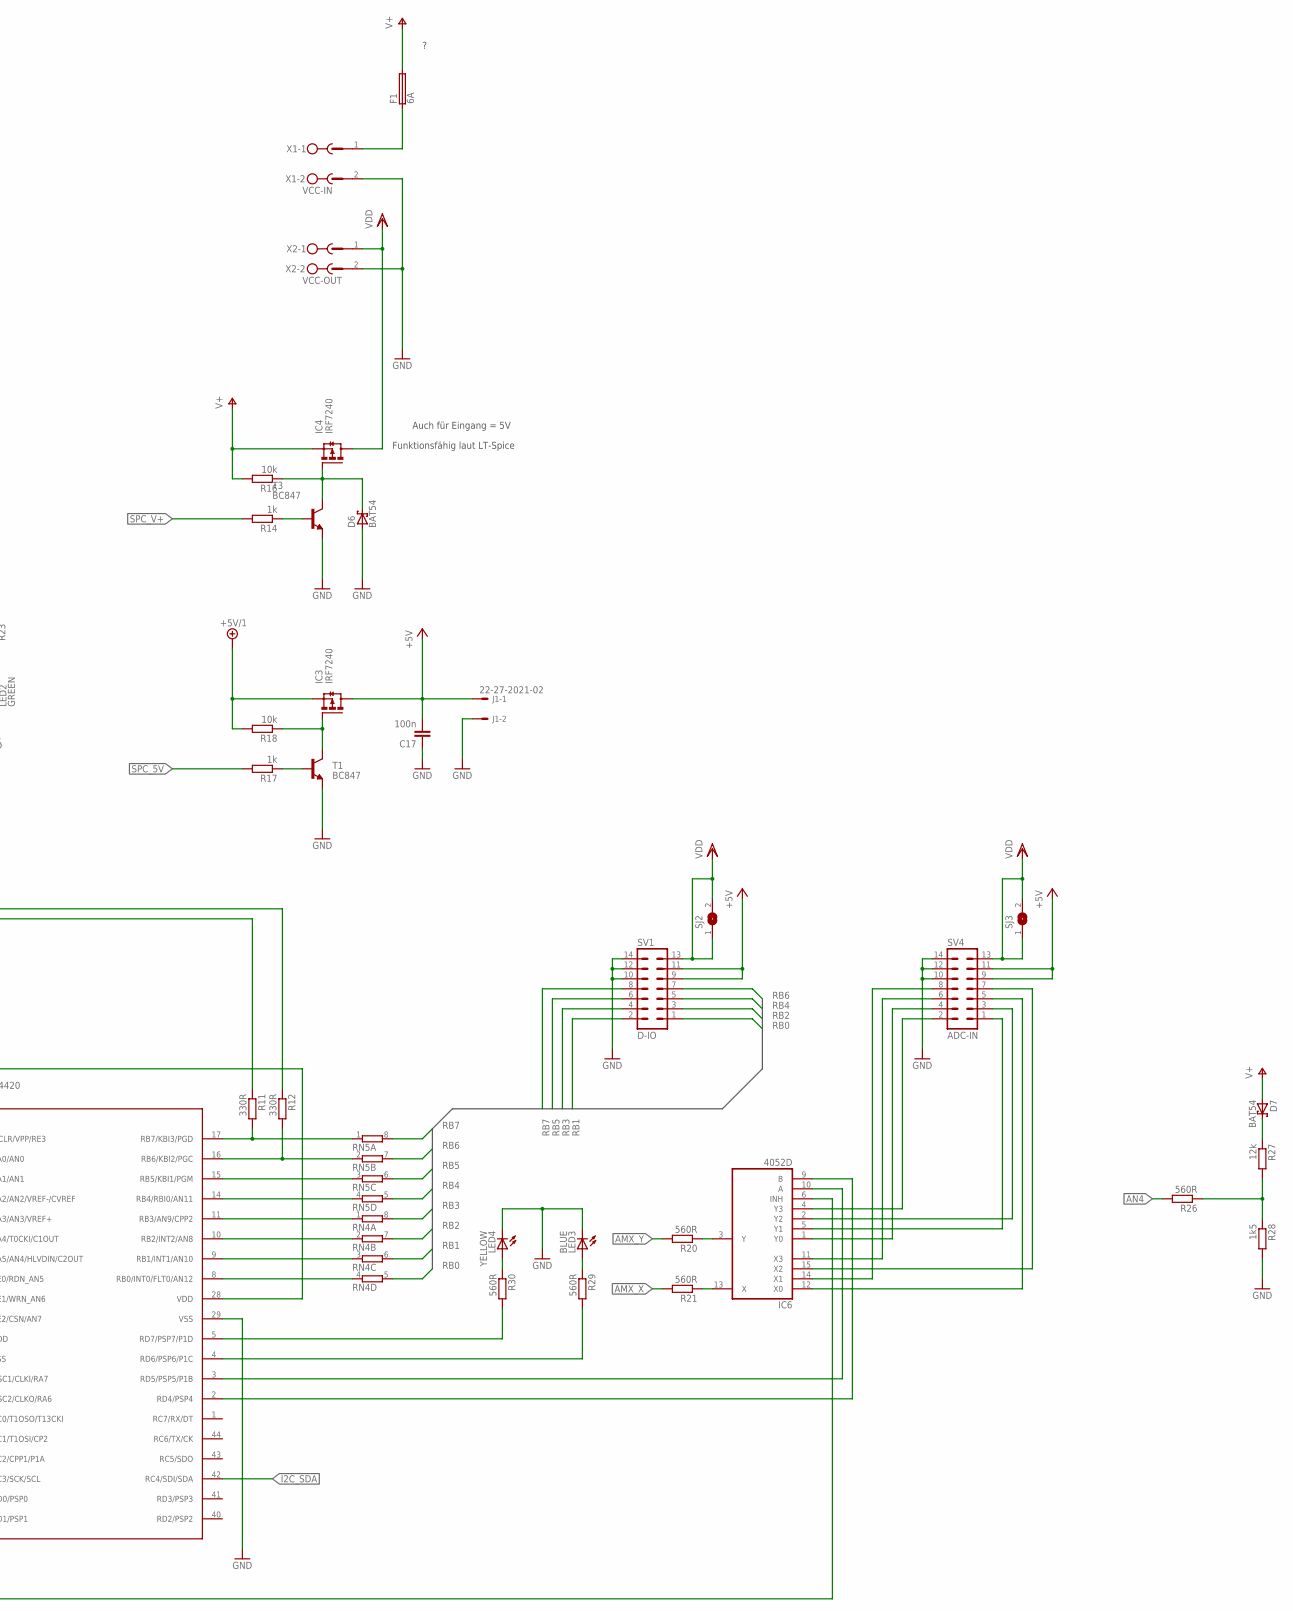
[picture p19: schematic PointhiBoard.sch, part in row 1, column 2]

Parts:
BAT1: CH25-2032LF
C1, C2: 10p; C0805
C3, C5, C8, C9, C10, C11, C12, C13, C16, C17: 100n; C0805
C4: 100p; C0805
C6, C7, C14, C15: 47µ; PANASONIC_D
D1, D5: SSB43L; DO214AA
D2, D3, D4, D6, D7: BAT54; SOT23
F1: 6A; SHK20L
IC1: MCP7940N; MSOP8
IC2: ADP2303ARDZ-5.0; SOIC8
IC3, IC4: IRF7240; SOIC8
IC5: 18F4420; TQFP44
IC6: 4052D; SO16
IC7: ADR02; SOIC8
J1: 22-27-2021-02; 6410-02
L1: PM127SH-4R7N-RC; PM127SH
LCD1: MI0283QT-9A
LED1: RED; CHIP-LED0805
LED2: GREEN; CHIP-LED0805
LED3: BLUE; CHIP-LED0805
LED4: YELLOW; CHIP-LED0805
Q1, Q2, Q3: BSS123; SOT23
Q4: 32.768KHZ; MM20SS
R1, R2, R3, R4, R5, R6, R16, R18, R25: 10k; R0805
R7: 10R; R0805
R8, R14, R17, R19, R24: 1k; R0805
R9: 100k; R0805
R10, R20, R21, R23, R26, R29, R30, R31, R32: 560R; R0805
R11, R12, R13, R15: 330R; R0805
R22: 2k2; R0805
R27: 12k; R0805
R28: 1k5; R0805
RN4, RN5: 4R-NEXB38V; EXB38V
SJ1, SJ2, SJ3: SJ
SV1: D-IO; 3M_14L
SV2: I2C; 3M_10L
SV3: ICSP; ML6
SV4: ADC-IN; 3M_14L
SV5: RS232_TTL; 1X04
T1, T3: BC847; SOT23
TP1, TP2, TP3, TP4, TP5, TP6, TP7, TP8: PTR1B2,54; B2,54
U$1: RASPBERRY-PI_REV2
X1: VCC-IN; MSTBV2
X2: VCC-OUT; MSTBV2

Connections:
+3V3: C3.2, IC1.8 (VCC), Q1.1 (G), Q2.1 (G), Q3.1 (G), R1.2, R2.2, R5.2, U$1.P1_1 (3V3)
+5V: C17.2, IC3.5 (D), IC3.6 (D), IC3.7 (D), IC3.8 (D), J1.1, R3.2, R4.2, R6.2, R23.1, SV1.9, SV1.11, SV2.5, SV2.7, SV4.9, SV4.11, TP5.TP
+5V/1: C7.+, C9.2, C13.2, C15.+, C16.2, D3.1 (A), IC2.5 (FB), IC3.1 (S), IC3.2 (S), IC3.3 (S), IC6.16 (VCC), L1.P$2, R18.2, R31.2, TP3.TP
+5V/2: LCD1.VCC_CON1@1 (VCC), LCD1.VCC_CON1@2 (VCC), R7.2, TP4.TP, U$1.P1_2 (5V), U$1.P1_4 (5V)
AMX_X: IC5.20 (RA1/AN1), R21.2
AMX_Y: IC5.19 (RA0/AN0), R20.2
AN4: IC5.24 (RA5/AN4/HLVDIN/C2OUT), R26.2
GND: C6.-, C7.-, C8.1, C9.1, C10.1, C11.1, C12.1, C13.1, C14.-, C15.-, C16.1, C17.1, D1.A, D6.1 (A), IC2.7 (GND), IC5.6 (VSS), IC5.29 (VSS), IC6.7 (VEE), IC6.8 (GND), IC7.4 (GND), J1.2, LED1.C, LED2.C, LED3.C, LED4.C, R13.2, R25.2, R28.2, R32.1, SV1.10, SV1.12, SV1.14, SV2.2, SV2.4, SV2.6, SV2.8, SV3.2, SV3.4, SV4.10, SV4.12, SV4.14, T1.2 (E), T3.2 (E), TP2.TP, X1.2, X2.2
GND1: BAT1.-, C1.2, C2.2, C3.1, C4.1, IC1.4 (VSS), LCD1.GND_CON1@1 (GND), LCD1.GND_CON1@2 (GND), R24.1, SV5.3, U$1.P1_9 (GND), U$1.P5_7 (GND), U$1.P5_8 (GND)
I2C_INT: Q3.3 (D), R6.1, SV2.10
I2C_SCL: IC5.37 (RC3/SCK/SCL), Q2.3 (D), R3.1, SV2.1
I2C_SCL_RASP: IC1.6 (SCL), Q2.2 (S), R2.1, U$1.P1_5 (GPIO3,I2C0_SCL)
I2C_SDA: IC5.42 (RC4/SDI/SDA), Q1.3 (D), R4.1, SV2.3
I2C_SDA_RASP: IC1.5 (SDA), Q1.2 (S), R1.1, U$1.P1_3 (GPIO2,I2C0_SDA)
MCLR: IC5.18 (MCLR/VPP/RE3), R25.1, SV3.6
unnamed: Q3.2 (S), R5.1, U$1.P1_7 (GPIO4,GPCLK0)
unnamed: LCD1.A-LCD_LED (LCD_LED), U$1.P1_18 (GPIO24)
unnamed: LCD1.A-LCD_RST (LCD_RST), U$1.P1_16 (GPIO23)
unnamed: LCD1.ADS_IRQ, U$1.P1_22 (GPIO25)
unnamed: R7.1, SV5.4
unnamed: R8.1, U$1.P1_8 (GPIO14,UART0_TXD)
unnamed: R8.2, SV5.2
unnamed: C5.2, D1.C, IC2.8 (SW), L1.P$1
unnamed: C8.2, D3.3 (C), D4.3 (C), IC5.7 (VDD), IC5.28 (VDD)
unnamed: C5.1, IC2.1 (BST)
unnamed: IC2.4 (PGOOD), R9.1
unnamed: IC5.17 (RB7/KBI3/PGD), R11.2, RN5.1
unnamed: IC5.16 (RB6/KBI2/PGC), R12.2, RN5.2 (1)
unnamed: C1.1, IC1.1 (X1), Q4.1
unnamed: C2.1, IC1.2 (X2), Q4.4 (2)
unnamed: D6.3 (C), IC4.4 (G), R16.1, T3.3 (C)
unnamed: R14.1, T3.1 (B)
unnamed: IC1.7 (MFP), TP1.TP
unnamed: IC5.15 (RB5/KBI1/PGM), RN5.3 (1)
unnamed: IC3.4 (G), R18.1, T1.3 (C)
unnamed: R17.1, T1.1 (B)
unnamed: IC5.14 (RB4/RBI0/AN11), RN5.4 (1)
unnamed: IC5.11 (RB3/AN9/CPP2), RN4.1
unnamed: F1.1A (1), X1.1
unnamed: IC5.10 (RB2/INT2/AN8), RN4.2 (1)
unnamed: IC5.9 (RB1/INT1/AN10), RN4.3 (1)
unnamed: IC5.8 (RB0/INT0/FLT0/AN12), RN4.4 (1)
unnamed: D4.1 (A), SV3.5
unnamed: C4.2, IC1.3 (VBAT), R19.2
unnamed: BAT1.+, D2.1 (A)
unnamed: D2.3 (C), R19.1
unnamed: D7.3 (C), R27.1
unnamed: R11.1, SV3.1
unnamed: R12.1, SV3.3
unnamed: IC6.1 (Y0), SV4.4
unnamed: IC6.2 (Y2), SV4.3
unnamed: IC6.4 (Y3), SV4.2
unnamed: IC6.5 (Y1), SV4.1
unnamed: IC6.15 (X2), SV4.7
unnamed: IC6.14 (X1), SV4.8
unnamed: IC6.12 (X0), SV4.5
unnamed: IC6.11 (X3), SV4.6
unnamed: IC5.3 (RD5/PSP5/P1B), IC6.10 (A)
unnamed: IC5.2 (RD4/PSP4), IC6.9 (B)
unnamed: IC5.32 (RC0/T1OSO/T13CKI), IC6.6 (INH)
unnamed: C10.2, IC7.6 (VOUT), R15.2, TP8.TP
unnamed: IC5.22 (RA3/AN3/VREF+), R15.1
unnamed: IC5.21 (RA2/AN2/VREF-/CVREF), R13.1
unnamed: IC6.13 (X), R21.1
unnamed: IC6.3 (Y), R20.1
unnamed: LED1.A, R22.2
unnamed: LED2.A, R23.2
unnamed: R10.1, R24.2, U$1.P1_10 (GPIO15,UART0_RXD)
unnamed: R10.2, SV5.1
unnamed: R26.1, R27.2, R28.1
unnamed: IC5.4 (RD6/PSP6/P1C), R29.2
unnamed: IC5.26 (RE1/WRN_AN6), R31.1, R32.2
unnamed: IC5.5 (RD7/PSP7/P1D), R30.2
unnamed: LED3.A, R29.1
unnamed: LED4.A, R30.1
RB0: RN4.5 (2), SV1.1
RB1: RN4.6 (2), SV1.2
RB2: RN4.7 (2), SV1.3
RB3: RN4.8 (2), SV1.4
RB4: RN5.5 (2), SV1.5
RB5: RN5.6 (2), SV1.6
RB6: RN5.7 (2), SV1.7
RB7: RN5.8 (2), SV1.8
SPC_5V: IC5.39 (RD1/PSP1), R17.2
SPC_V+: IC5.38 (RD0/PSP0), R14.2
SPI_CE0: LCD1.A-ADS_CS (ADS_CS), U$1.P1_24 (GPIO8,SPI0_CE0)
SPI_CE1: LCD1.A-LCD_CS (LCD_CS), U$1.P1_26 (GPIO7,SPI0_CE1)
SPI_MISO: LCD1.SDO, U$1.P1_21 (GPIO9_MISO)
SPI_MOSI: LCD1.A-SDI (SDI), U$1.P1_19 (GPIO10_MOSI)
SPI_SCLK: LCD1.A-SCL (SCL), U$1.P1_23 (GPIO11_SCLK)
V+: D5.A, D7.1 (A), F1.2A (2), IC4.1 (S), IC4.2 (S), IC4.3 (S), R16.2, TP7.TP
VCC/2: C6.+, C11.2, C12.2, C14.+, D5.C, IC2.2 (VIN), IC2.3 (EN), IC7.2 (VIN), R9.2
VDD: IC4.5 (D), IC4.6 (D), IC4.7 (D), IC4.8 (D), R22.1, SJ1.1, SJ1.2, SJ2.1, SJ2.2, SJ3.1, SJ3.2, SV1.13, SV2.9, SV4.13, TP6.TP, X2.1

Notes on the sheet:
Funktionsfähig laut LT-Spice
Auch für Eingang = 5V

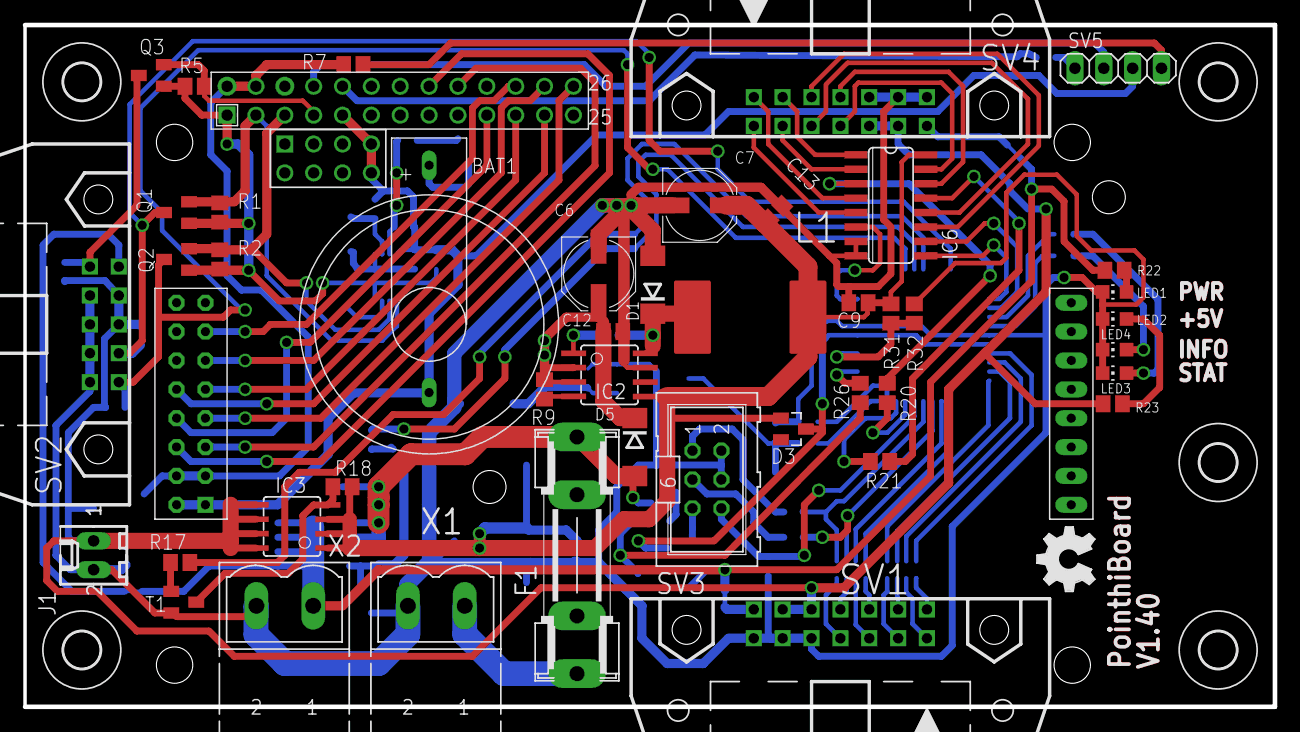
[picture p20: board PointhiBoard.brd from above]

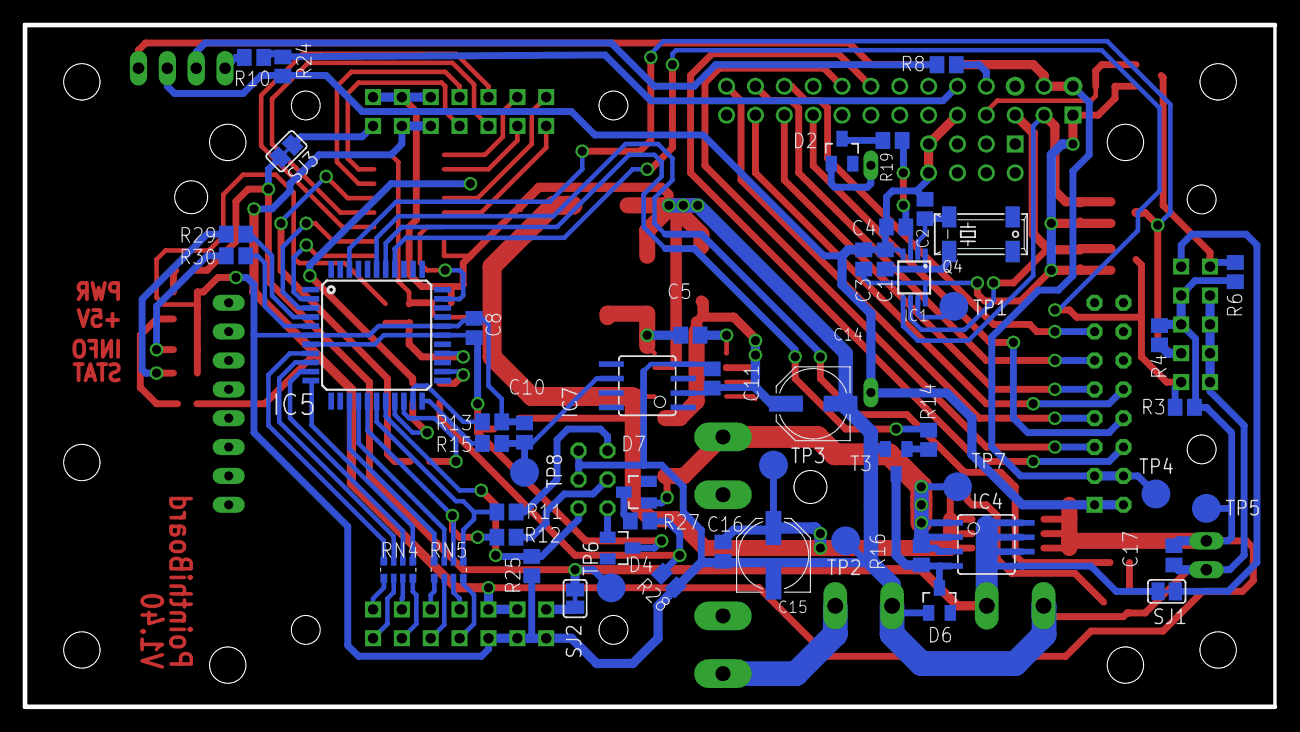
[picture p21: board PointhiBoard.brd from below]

Board: 2 copper layers, 110.0 x 60.0 mm, 105 parts (53 on the bottom side), 93 nets.

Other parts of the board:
U$2, U$3, U$4, U$5, U$6: 3,2
U$7: OSHW_FILLX200_NOTEXT

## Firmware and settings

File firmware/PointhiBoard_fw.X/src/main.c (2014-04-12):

/**
 * @file main.c
 *
 * @author thomas
 *
 * @date 1. March 2014
 * @copyright GNU General Public License (GPL) 3.0
 */

#include <pic18.h>

#include "define.h"
#include "init.h"
#include "io.h"
#include "adc.h"
#include "time.h"

#ifdef __TEST
    #include "test.h"
    #warning "Compiling Test-Code!"
#endif

// Setting Config-Bits
#ifdef __OSC_INTOSC
    #pragma config IESO = OFF, OSC = INTIO67, FCMEN = OFF               // CONFIG 1H        // Internal Oscilator
#else
    #pragma config IESO = OFF, OSC = HS, FCMEN = OFF                    // CONFIG 1H        // External Oscillator
#endif
#pragma config BOREN = OFF, PWRT = OFF                                  // CONFIG 2L
#pragma config WDT = OFF                                                // CONFIG 2H
#pragma config CCP2MX = PORTC, PBADEN = OFF, LPT1OSC = OFF, MCLRE = OFF // CONFIG 3H
#pragma config STVREN = OFF, LVP = OFF, XINST = OFF, DEBUG = OFF        // CONFIG 4L
#pragma config CP0 = OFF, CP1 = OFF                                     // CONFIG 5L
#pragma config CPD = OFF, CPB = OFF                                     // CONFIG 5H
#pragma config WRT0 = OFF, WRT1 = OFF                                   // CONFIG 6L
#pragma config WRTB = OFF, WRTC = OFF, WRTD = OFF                       // CONFIG 6H
#pragma config EBTR0 = OFF, EBTR1 = OFF                                 // CONFIG 7L
#pragma config EBTRB = OFF                                              // CONFIG 7H

// Main-Function

void main() {

    InitSystem();

    InitStartSequence();

#ifdef __TEST
    IoSetLedInfo(LED_BLINK_FAST);
    IoSetLedStat(LED_BLINK_FAST);
    unsigned char returnValue = TestRun();
    if(returnValue) {
        IoSetLedInfo(LED_PEAK_SLOW);
        IoSetLedStat(LED_OFF);

    } else {
        IoSetLedInfo(LED_OFF);
        IoSetLedStat(LED_ON);
    }
    
    while (1) {
    }
#endif

    while (1) {

    }
}

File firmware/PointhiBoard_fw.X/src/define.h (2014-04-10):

/**
 * @file define.h
 *
 * @author thomas
 *
 * @date 1. March 2014
 * @copyright GNU General Public License (GPL) 3.0
 */

#ifndef DEFINE_H
#define	DEFINE_H

#include <pic18.h>

// Using the internal oscillator
#define __OSC_INTOSC 1

#define _XTAL_FREQ 8000000

// Pins which are used by the fet's and led's

#define o_FET_VCC               LATDbits.LATD0
#define o_FET_5V                LATDbits.LATD1
#define o_LED_STAT              LATDbits.LATD6
#define o_LED_INFO              LATDbits.LATD7

// Pins which are used by the analoge multiplexer

#define o_ADC_MPX_A             LATDbits.LATD5
#define o_ADC_MPX_B             LATDbits.LATD4
#define o_ADC_MPX_INH           LATCbits.LATC0

#define FET_OFF                 0x00
#define FET_ON                  0xFF

// Different flashing pattern for the led's

#define LED_OFF                 0x00
#define LED_ON                  0xFF
#define LED_BLINK_SLOW          0xF0
#define LED_BLINK_SLOW_INVERTED 0x0F
#define LED_BLINK_FAST          0xAA
#define LED_BLINK_FAST_INVERTED 0x55
#define LED_PEAK_SLOW           0x80
#define LED_PEAK_SLOW_INVERTED  0x08
#define LED_PEAK_FAST           0x88
#define LED_PEAK_FAST_INVERTED  0x22

// Multiplexer

#define MPX_PIN_0               0x00
#define MPX_PIN_1               0x01
#define MPX_PIN_2               0x02
#define MPX_PIN_3               0x03

// ADC-Port definitions

#define ADC_PORT_MPX_Y          0
#define ADC_PORT_MPX_X          1
#define ADC_PORT_5V             4
// Rev-1.3 manual connected!
#define ADC_PORT_VCC            5

// ADC-Array definitions

#define ADC_ARRAY_VCC           0
#define ADC_ARRAY_5V            1
#define ADC_ARRAY_AI            2
#define ADC_ARRAY_MPX_Y         ADC_ARRAY_AI
#define ADC_ARRAY_MPX_X         (ADC_ARRAY_AI + 4)


// Define the voltage divider on the input for the ADC

#define ADC_MULTIPLIER_MPX      1
#define ADC_MULTIPLIER_5V       2
#define ADC_MULTIPLIER_VCC      9

// I2C

#define I2C_DEFAULT_ADRESS      0xC0

#endif	/* DEFINE_H */

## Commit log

2014-03-01 adding current files
    [PointhiBoard.brd, PointhiBoard.sch]
2014-03-02 fix wrong adc-port, little layout modifies
    [PointhiBoard.brd, PointhiBoard.sch]
2014-03-29 Adding full ADC-Support
2014-03-29 adding test-function and Interrupt driven timer-function
2014-04-10 fix adc
    ADC is now working correctly
    [adc.c, define.h, main.c]
2014-04-12 Initial working I2C-Implementation
2014-04-12 add via i2c set and readeable registers
2014-04-23 upload .pdf of current german-documentation
2014-04-24 fix position and orentation of text(values, names,...) on the pcb
    [PointhiBoard.brd, PointhiBoard.sch]
2014-04-24 fix hole-diameter of con-harting-ml
    [PointhiBoard.brd, PointhiBoard.sch]
2014-04-24 fix warnings on pcb
    [PointhiBoard.brd, PointhiBoard.sch]
2014-05-22 adding simple library and example-code to work with the board
2014-07-06 update pcb
    [PointhiBoard.brd, PointhiBoard.sch]
